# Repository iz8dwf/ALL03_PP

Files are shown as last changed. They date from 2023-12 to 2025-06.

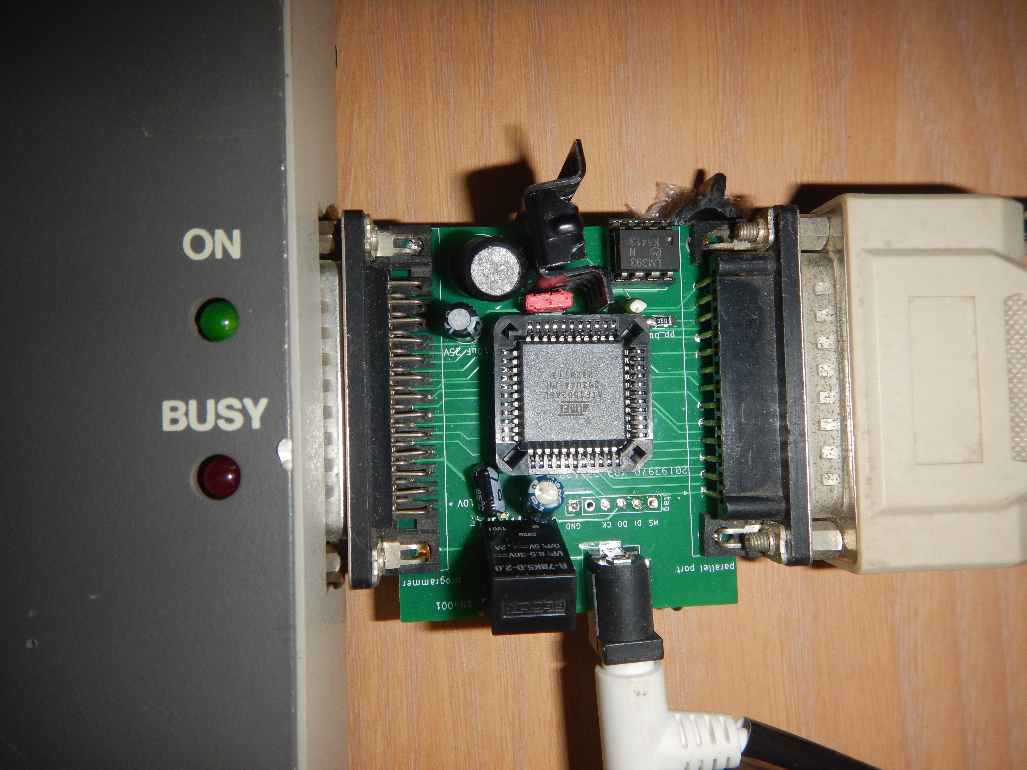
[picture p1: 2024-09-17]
images/DSCN4933.JPG

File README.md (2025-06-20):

# ALL03_PP
Hi-Lo ALL-03 and MOD-EMUP programmers parallel port interface using the ATF-1502 CPLD.

This is a circuit that allows to use the Hi-Lo ALL-03 (and clones like the
MOD-EMUP) universal programmers/testers via the parallel port interface
using a patched DOSBOX. Original design by Nicola Di Lieto used an EPM7032
CPLD. I've used an ATF1502 CPLD that's still in production.

*** The JTAG port has a non-standard pinout *** 

The 2SB794 PNP darlington transistor can be substituted with a similar PNP
darlington. Using a normal PNP transistor with HFE < 200 makes this switching
voltage inverter misbehave. You can attempt to change the base resistor from
4k7 ohms to 2k2 ohms to make a lower HFE transistor work.

USE AT YOUR OWN RISK! 

PS: I believe a similar approach can be used also for the older CSA-0x ISA card based programmers (HI-LO EPP-0x and ALL-01 for example). Of course the adapter
board must be re-designed and a different patch needs to be created for dosbox. If you are interested (I still have an EPP-04, but I'm not going to use it anymore anytime soon) in such an adapter and want to help, contact me.

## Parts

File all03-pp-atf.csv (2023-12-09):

Id | Designator | Package | Quantity | Designation | Supplier and ref
1 | C1,C9 | CP_Radial_D5.0mm_P2.50mm | 2 | 10uF 25V
2 | C2 | CP_Radial_D5.0mm_P2.50mm | 1 | 10uF 10V
3 | C3,C4 | C_0805_HandSoldering | 2 | 100n
4 | C7 | C_Rect_L7.0mm_W2.5mm_P5.00mm | 1 | 100n
5 | C8 | C_Disc_D3.8mm_W2.6mm_P2.50mm | 1 | 22p
6 | D1 | D_DO-41_SOD81_P10.16mm_Horizontal | 1 | 1N4001
7 | D2 | D_SMA-SMB_Universal_Handsoldering | 1 | V8PAL45 K
8 | J1 | BARREL_JACK | 1 | 12V IN
9 | J2 | DSUB-25_Male_Horizontal_Pitch2.77x2.84mm_EdgePinOffset4.94mm_Housed_MountingHolesOffset7.48mm | 1 | parallel port
10 | J3 | Pin_Header_Straight_1x06_Pitch2.54mm | 1 | jtag
11 | J4 | DSUB-25_Female_Horizontal_Pitch2.77x2.84mm_EdgePinOffset4.94mm_Housed_MountingHolesOffset7.48mm | 1 | programmer
12 | JP1 | R_1206_HandSoldering | 1 | pp_busy
13 | L1 | L_Radial_D10.0mm_P5.00mm_Fastron_07P | 1 | 33uH
14 | Q1 | TO-126_Vertical | 1 | BD138
15 | R1 | R_0805_HandSoldering | 1 | 10k
16 | R2,R3,R5,R6,R7,R8 | R_0805_HandSoldering | 6 | 100k
17 | R4 | R_0805_HandSoldering | 1 | 47k
18 | R9 | R_0805_HandSoldering | 1 | 1k
19 | R10 | R_0805_HandSoldering | 1 | 4k7
20 | U1 | TO-220-3_Vertical | 1 | R-78k5.0-1.0
21 | U2 | PLCC44 | 1 | ATF1502AS-J
22 | U3 | DIP-8_W7.62mm_Socket | 1 | LM393

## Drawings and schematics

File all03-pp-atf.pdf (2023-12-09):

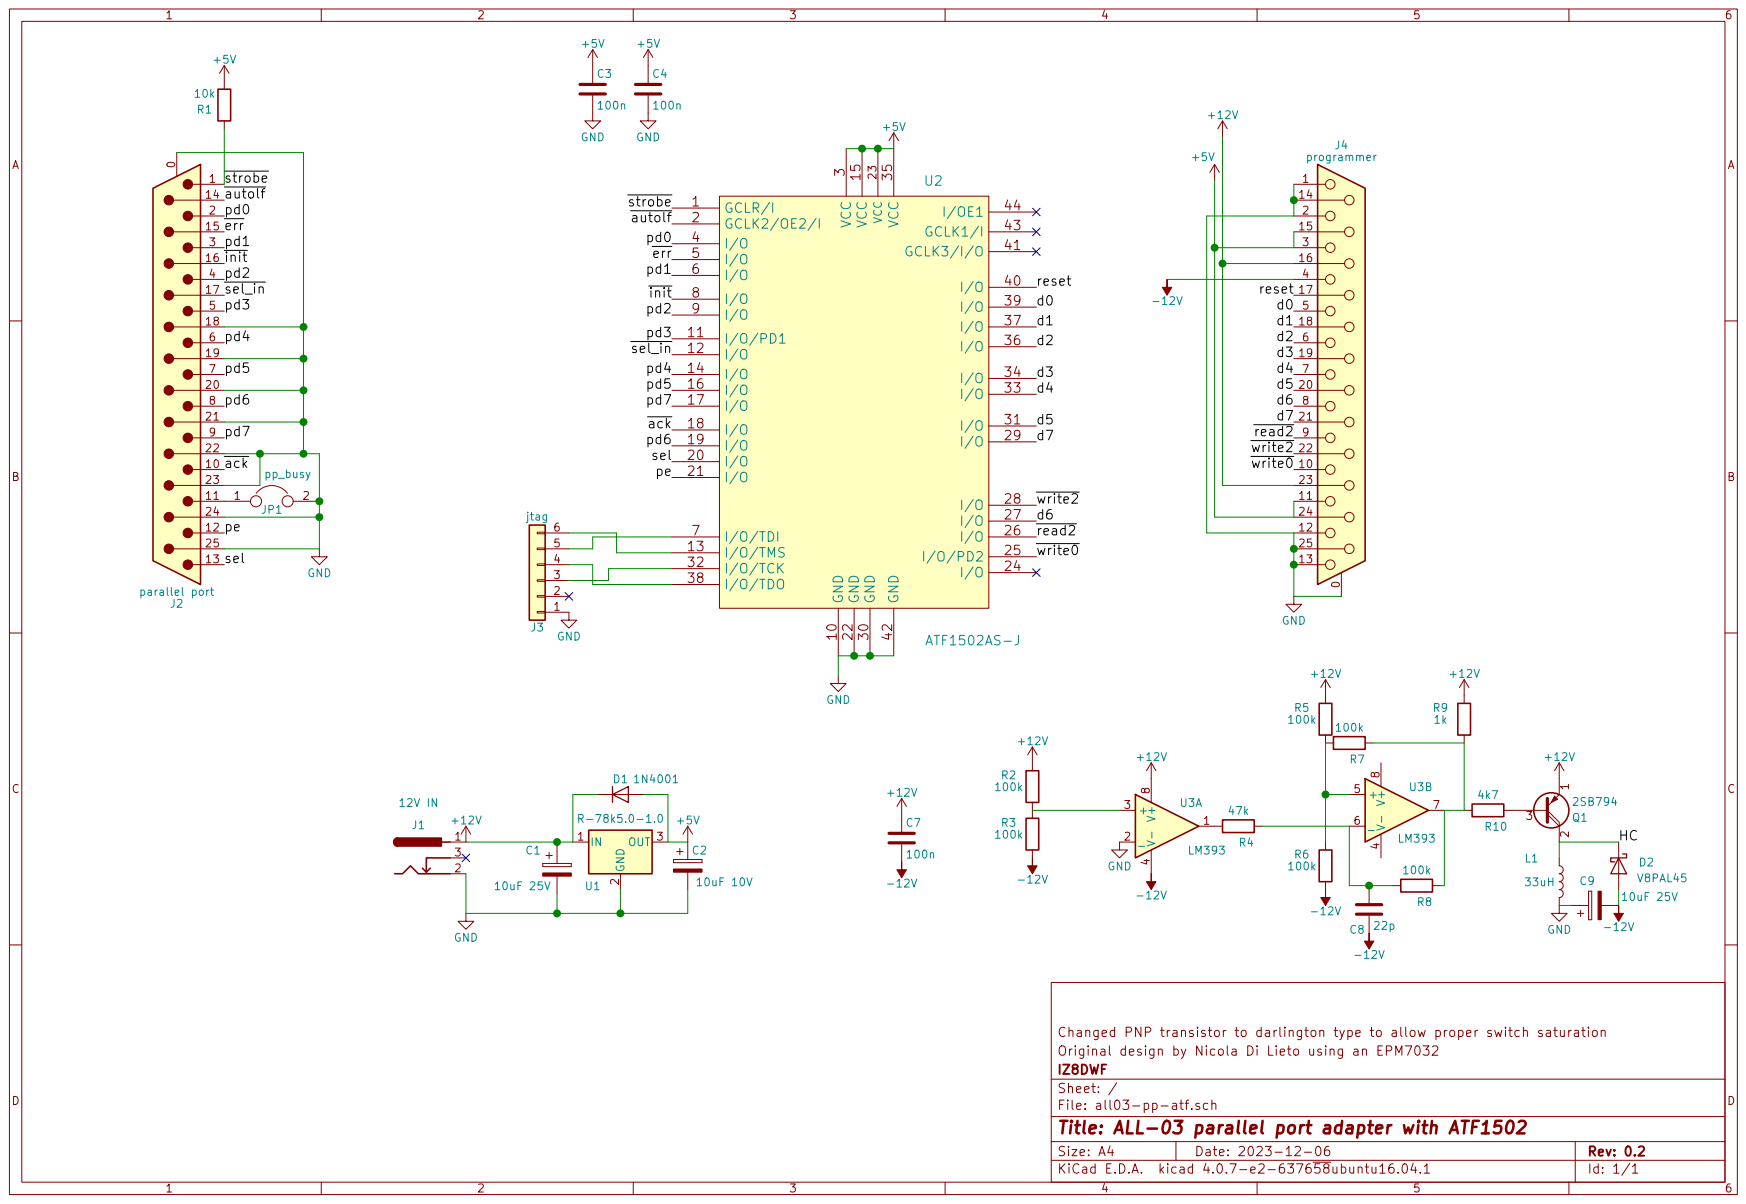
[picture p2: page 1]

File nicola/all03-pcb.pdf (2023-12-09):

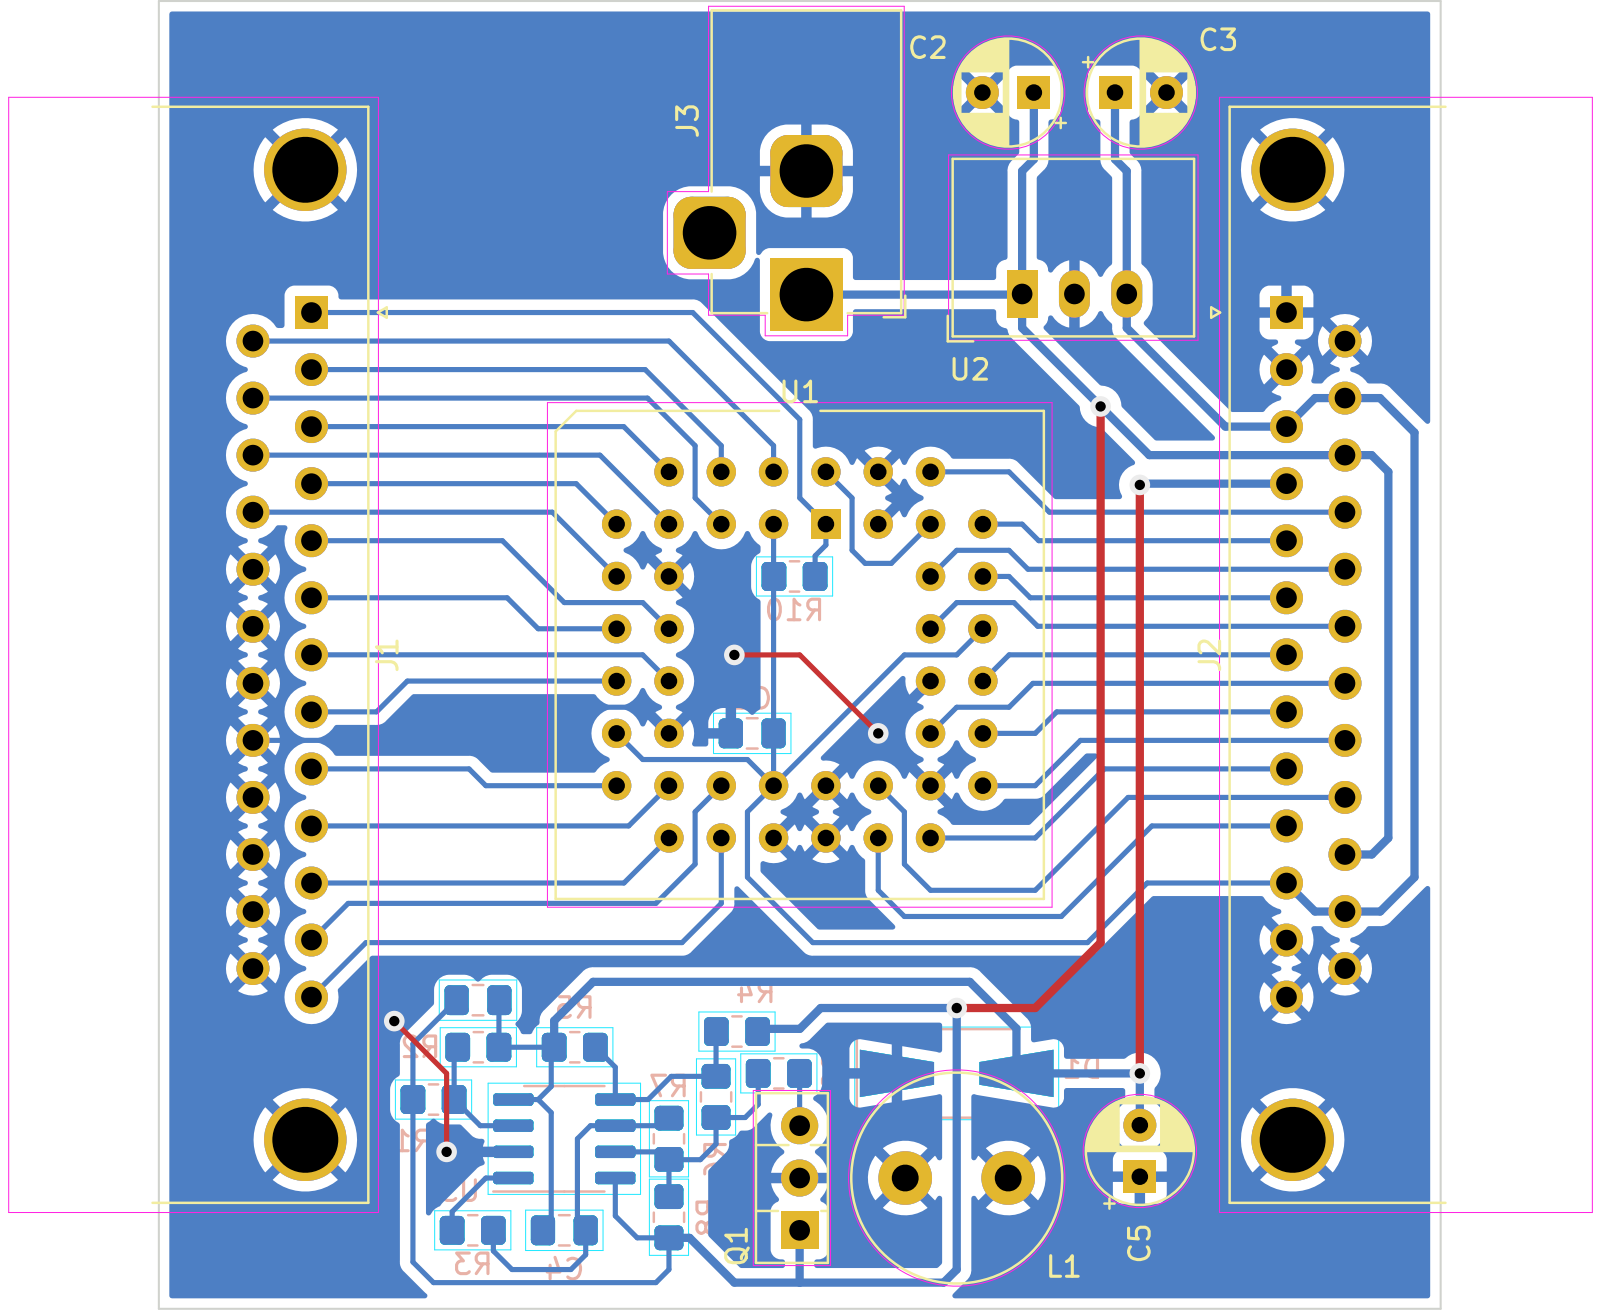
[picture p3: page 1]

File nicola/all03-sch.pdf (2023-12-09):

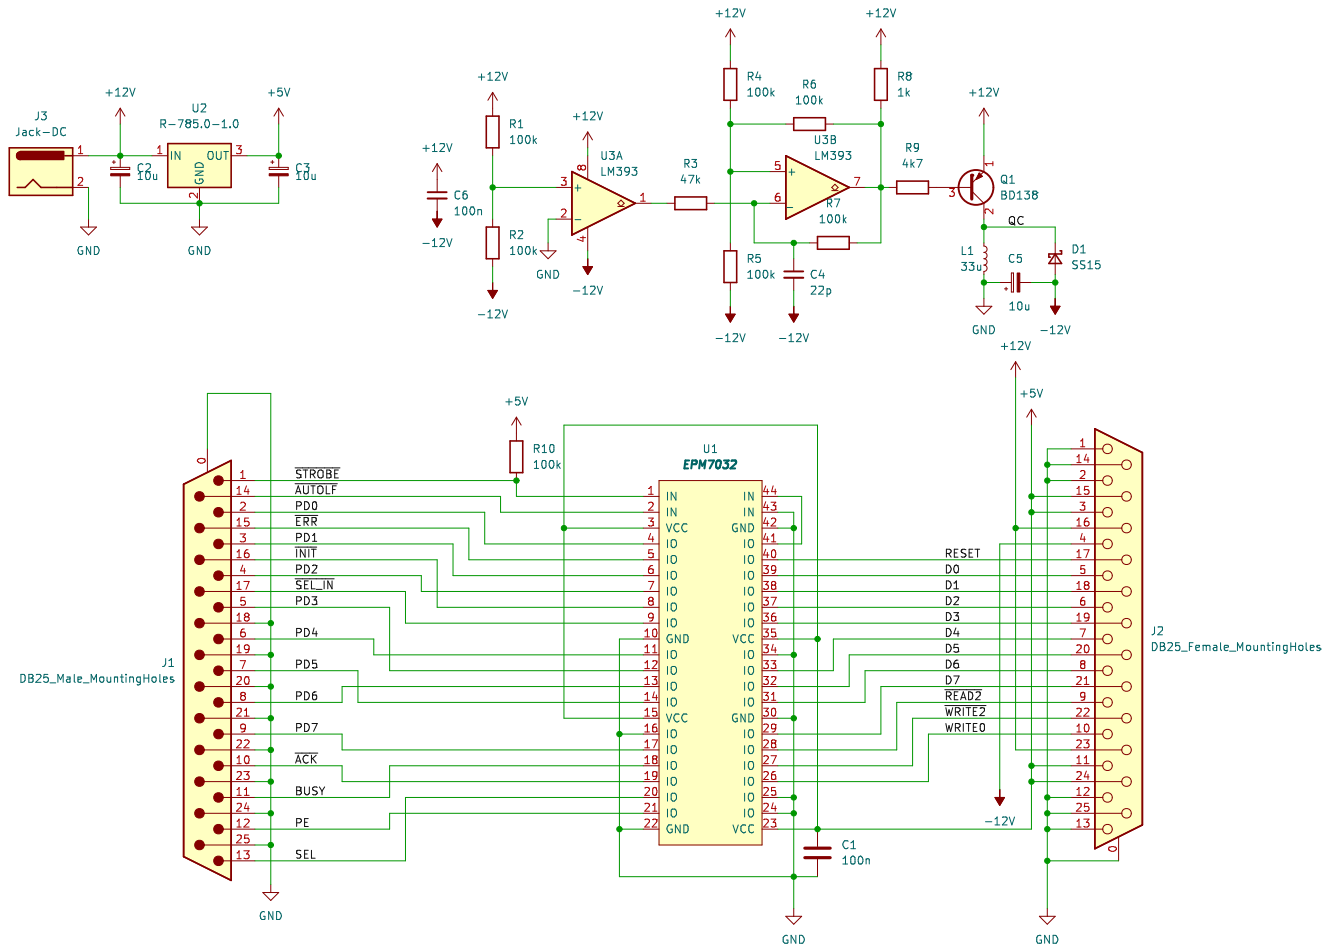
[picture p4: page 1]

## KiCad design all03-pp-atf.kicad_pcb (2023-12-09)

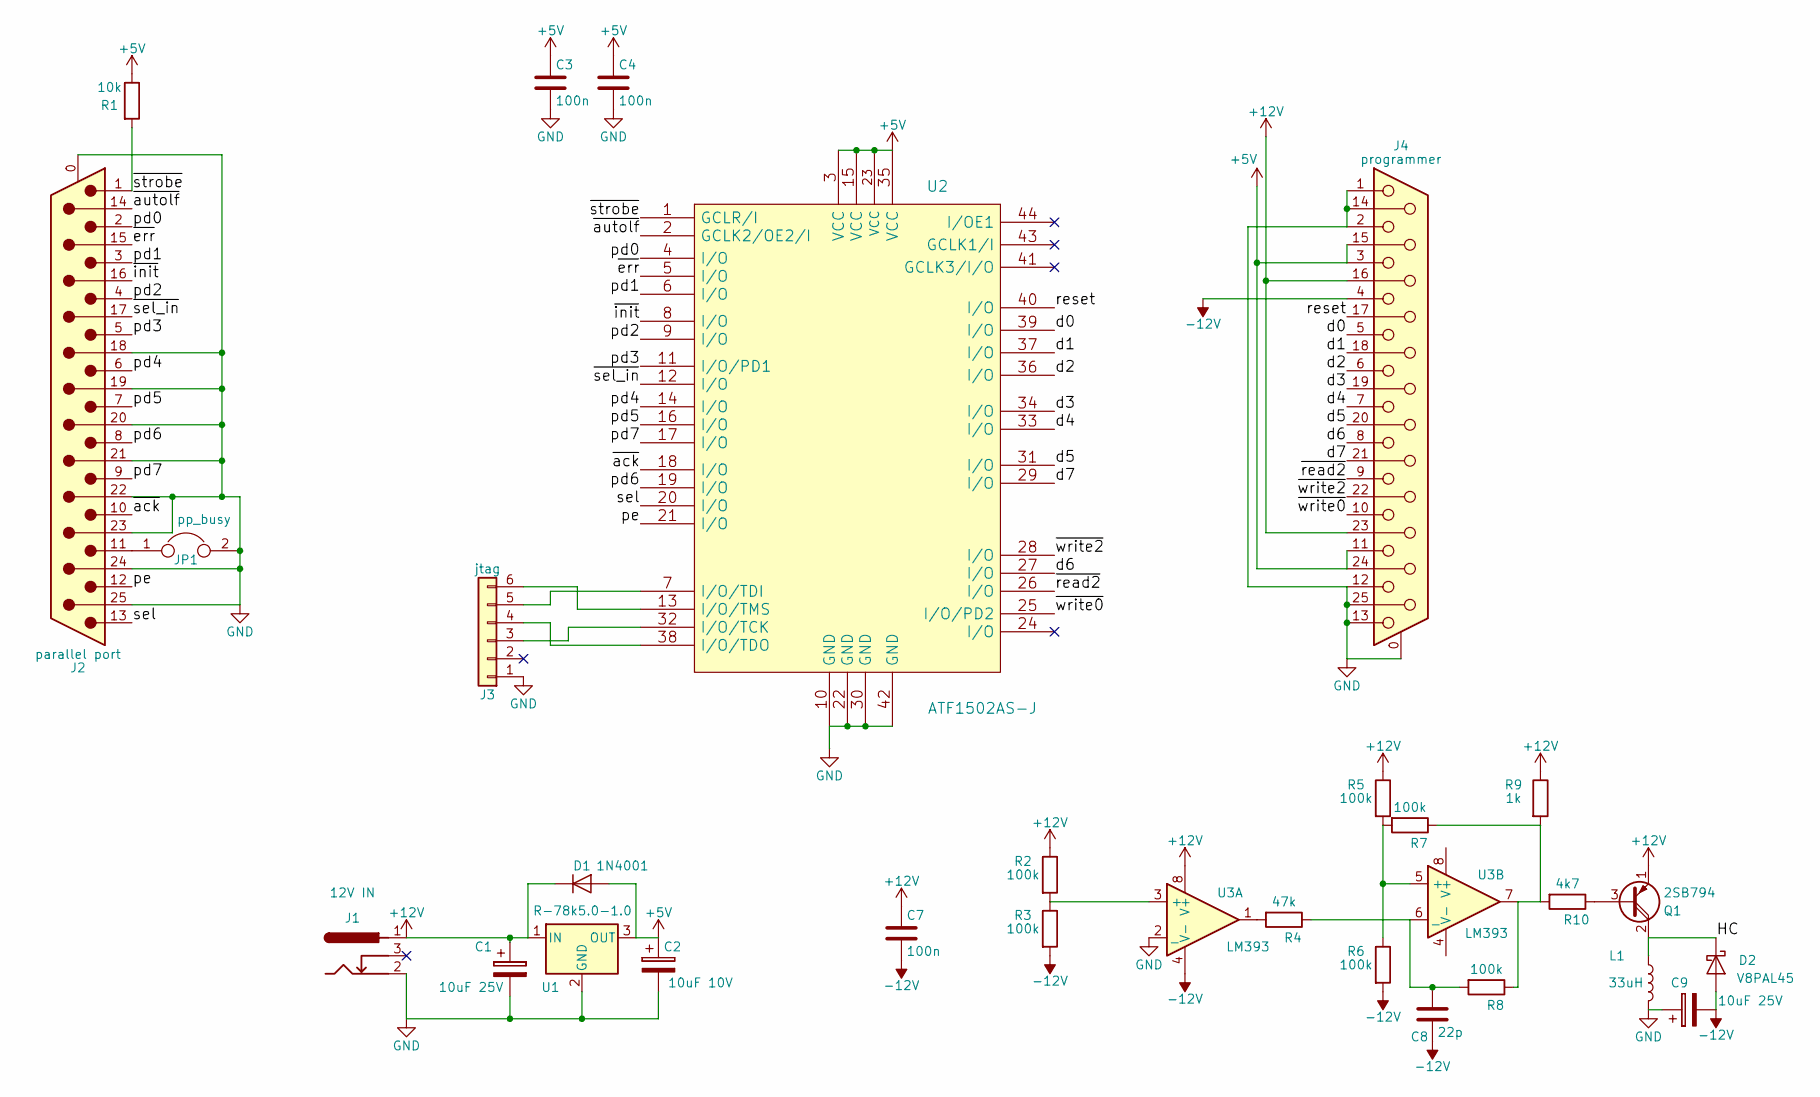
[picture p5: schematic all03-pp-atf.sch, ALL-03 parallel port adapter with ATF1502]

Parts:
C1, C9: 10uF 25V; CP_Radial_D5.0mm_P2.50mm
C2: 10uF 10V; CP_Radial_D5.0mm_P2.50mm
C3, C4: 100n; C_0805_HandSoldering
C7: 100n; C_Rect_L7.0mm_W2.5mm_P5.00mm
C8: 22p; C_Disc_D3.8mm_W2.6mm_P2.50mm
D1: 1N4001; D_DO-41_SOD81_P10.16mm_Horizontal
D2: V8PAL45; D_SMA-SMB_Universal_Handsoldering
J1: 12V IN; BARREL_JACK
J2: parallel port; DSUB-25_Male_Horizontal_Pitch2.77x2.84mm_EdgePinOffset4.94m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
J3: jtag; Pin_Header_Straight_1x06_Pitch2.54mm
J4: programmer; DSUB-25_Female_Horizontal_Pitch2.77x2.84mm_EdgePinOffset4.9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
JP1: pp_busy; R_1206_HandSoldering
L1: 33uH; L_Radial_D10.0mm_P5.00mm_Fastron_07P
Q1: 2SB794
R1: 10k; R_0805_HandSoldering
R2, R3, R5, R6, R7, R8: 100k; R_0805_HandSoldering
R4: 47k; R_0805_HandSoldering
R9: 1k; R_0805_HandSoldering
R10: 4k7; R_0805_HandSoldering
U1: R-78k5.0-1.0; TO-220-3_Vertical
U2: ATF1502AS-J; PLCC44
U3: LM393; DIP-8_W7.62mm_Socket

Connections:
+5V: C2.1, C3.1, C4.1, D1.2 (A), J4.3, J4.11, J4.15, J4.24, R1.1, U1.3 (OUT), U2.3 (VCC), U2.15 (VCC), U2.23 (VCC), U2.35 (VCC)
+12V: C1.1, C7.1, D1.1 (K), J1.1, J4.16, J4.23, Q1.1 (E), R2.1, R5.1, R9.1, U1.1 (IN), U3.8 (V+)
-12V: C7.2, C8.2, C9.2, D2.2 (A), J4.4, R3.2, R6.2, U3.4 (V-)
/HC: D2.1 (K), L1.1, Q1.2 (C)
/d0: J4.5, U2.39 (I/O)
/d1: J4.18, U2.37 (I/O)
/d2: J4.6, U2.36 (I/O)
/d3: J4.19, U2.34 (I/O)
/d4: J4.7, U2.33 (I/O)
/d5: J4.20, U2.31 (I/O)
/d6: J4.8, U2.27 (I/O)
/d7: J4.21, U2.29 (I/O)
/pd0: J2.2, U2.4 (I/O)
/pd1: J2.3, U2.6 (I/O)
/pd2: J2.4, U2.9 (I/O)
/pd3: J2.5, U2.11 (I/O/PD1)
/pd4: J2.6, U2.14 (I/O)
/pd5: J2.7, U2.16 (I/O)
/pd6: J2.8, U2.19 (I/O)
/pd7: J2.9, U2.17 (I/O)
/pe: J2.12, U2.21 (I/O)
/reset: J4.17, U2.40 (I/O)
/sel: J2.13, U2.20 (I/O)
/~ack: J2.10, U2.18 (I/O)
/~autolf: J2.14, U2.2 (GCLK2/OE2/I)
/~err: J2.15, U2.5 (I/O)
/~init: J2.16, U2.8 (I/O)
/~read2: J4.9, U2.26 (I/O)
/~sel_in: J2.17, U2.12 (I/O)
/~strobe: J2.1, R1.2, U2.1 (GCLR/I)
/~write0: J4.10, U2.25 (I/O/PD2)
/~write2: J4.22, U2.28 (I/O)
GND: C1.2, C2.2, C3.2, C4.2, C9.1, J1.2, J2.0 (PAD), J2.18, J2.19, J2.20, J2.21, J2.22, J2.23, J2.24, J2.25, J3.1, J4.0 (PAD), J4.1, J4.2, J4.12, J4.13, J4.14, J4.25, JP1.2, L1.2, U1.2 (GND), U2.10 (GND), U2.22 (GND), U2.30 (GND), U2.42 (GND), U3.2 (_)
unnamed: C8.1, R4.1, R8.2, U3.6 (_)
unnamed: J2.11, JP1.1
unnamed: J3.3, U2.32 (I/O/TCK)
unnamed: J3.4, U2.38 (I/O/TDO)
unnamed: J3.5, U2.7 (I/O/TDI)
unnamed: J3.6, U2.13 (I/O/TMS)
unnamed: Q1.3 (B), R10.1
unnamed: R2.2, R3.1, U3.3 (+)
unnamed: R4.2, U3.1
unnamed: R5.2, R6.1, R7.2, U3.5 (+)
unnamed: R7.1, R8.1, R9.2, R10.2, U3.7

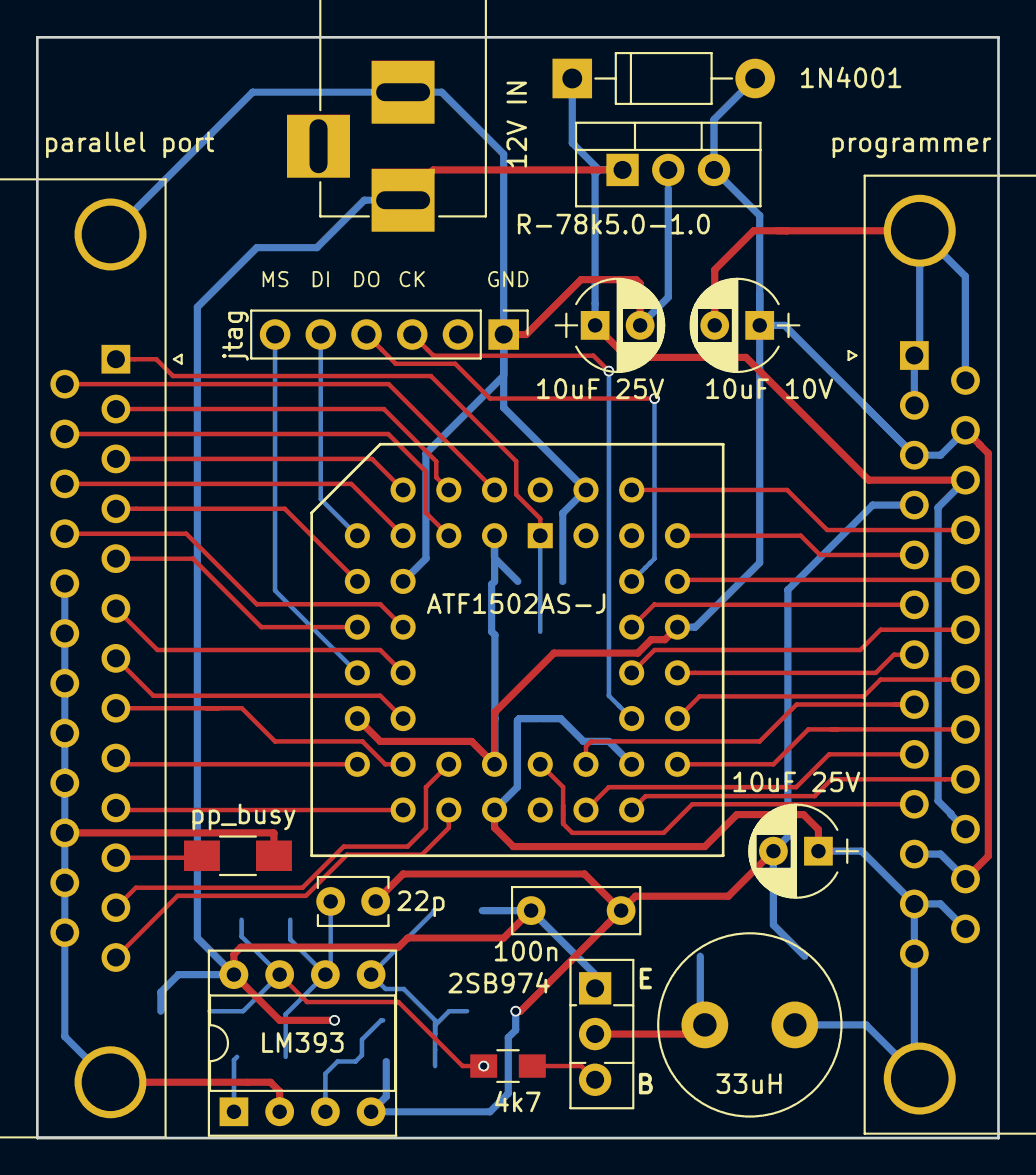
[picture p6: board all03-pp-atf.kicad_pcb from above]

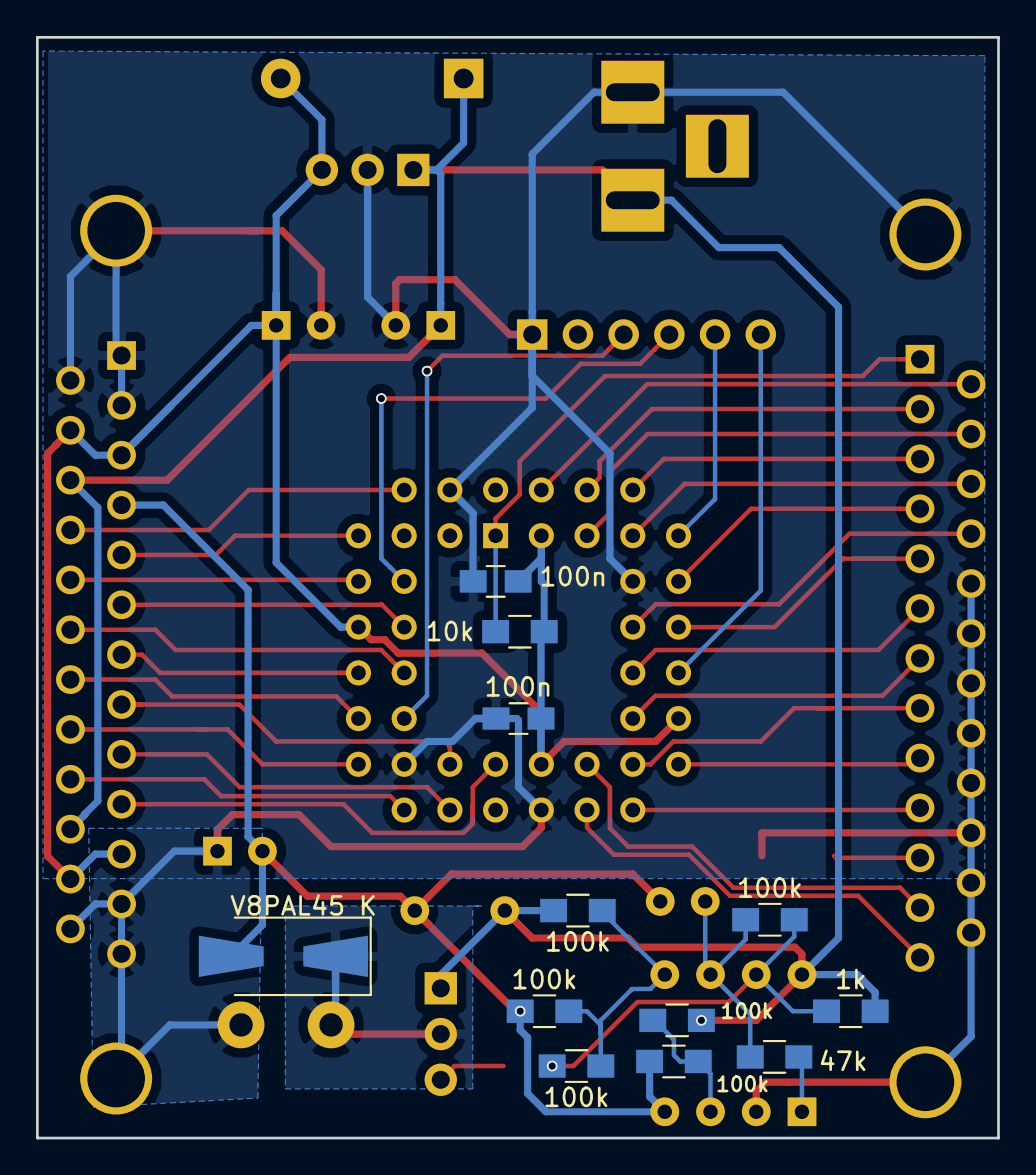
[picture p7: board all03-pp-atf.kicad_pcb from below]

Board: 2 copper layers, 53.4 x 61.1 mm, 29 parts (12 on the bottom side), 44 nets.

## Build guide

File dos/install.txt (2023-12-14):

cd into dosbox source directory

patch -p1 < 01-parport-passthrough.patch
patch -p1 < 02-parport-sac.patch
autoreconf -f -i
./configure
make
make install
